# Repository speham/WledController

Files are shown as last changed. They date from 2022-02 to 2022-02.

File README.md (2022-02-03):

# WledController

## Controller based on Esp8266-12F  for https://github.com/Aircoookie/WLED.git 

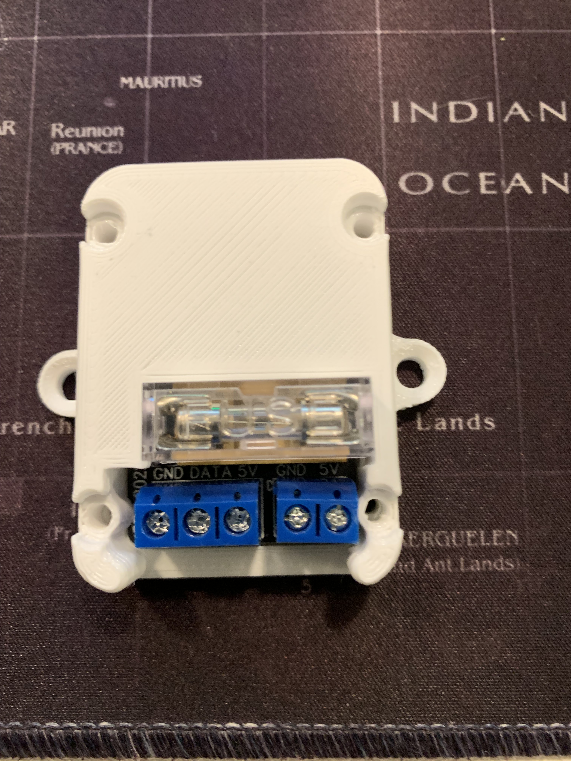
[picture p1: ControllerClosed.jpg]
board


## Settings / Features
- SW Button - GPIO0  
- Data Pin  - GPIO2
- Serial Connection for flashing
- use fuse depending on maximum current of Led stripe (max 5A)
- OTA-Update possible
- small form factor (41x55x21mm)

## Compatible Led Stripes
WS2812B | 5v | RGB
SK6812  | 5v | RGBW

## Connections
Connect 5V/GND to power supply. 5V out should only be used for LED stripes with less than 60 Leds (3.6A - ws2812b)
For longer stripes only the data wire of the stripe should be connected to the controller so + and - of the LED stripe 
is connected to the power supply (common GND for controller and led stripe).

## Flash With Other Firmware
Serial connector on top right side of the board (FTDI adapter necessary to flash)
 - Hold boot and RST button
 - release RST button 
 -> brings the esp8266 in flash mode

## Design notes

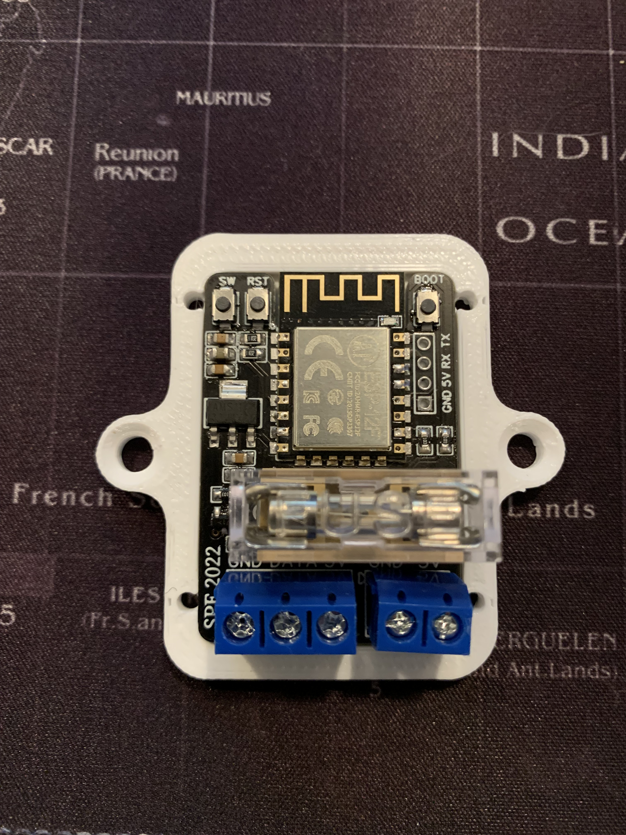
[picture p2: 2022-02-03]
ControllerOpen.jpg

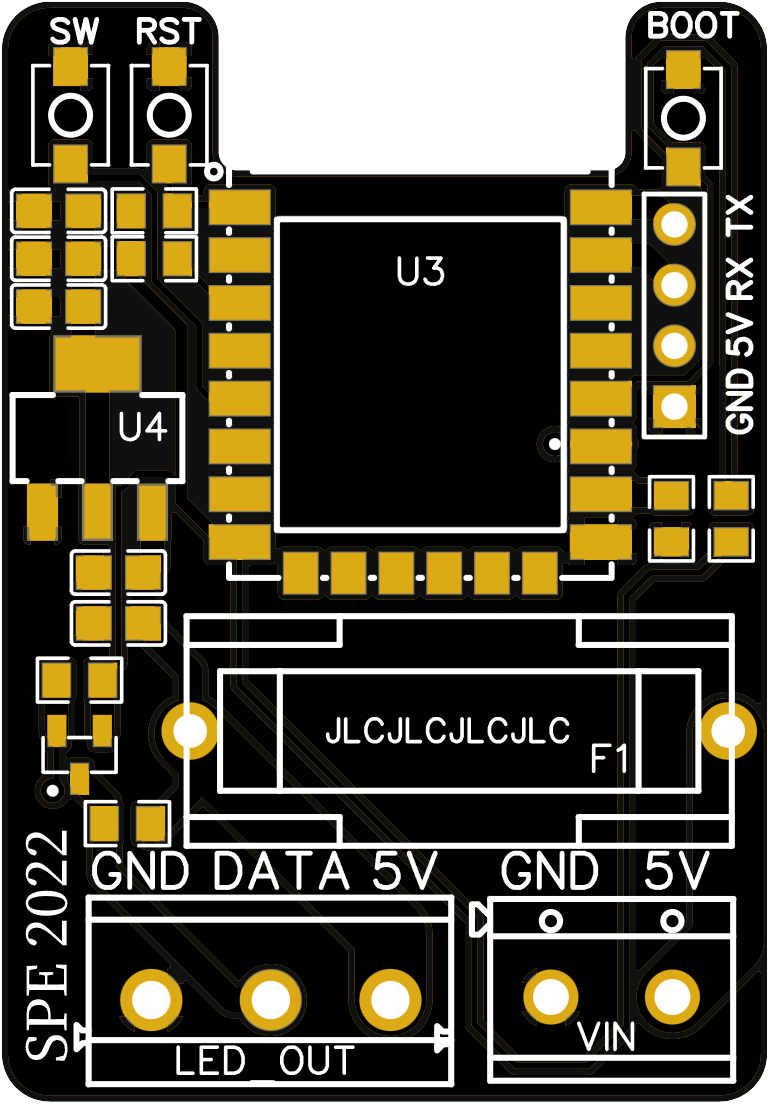
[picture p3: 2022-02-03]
PCB/PCB_V1.png

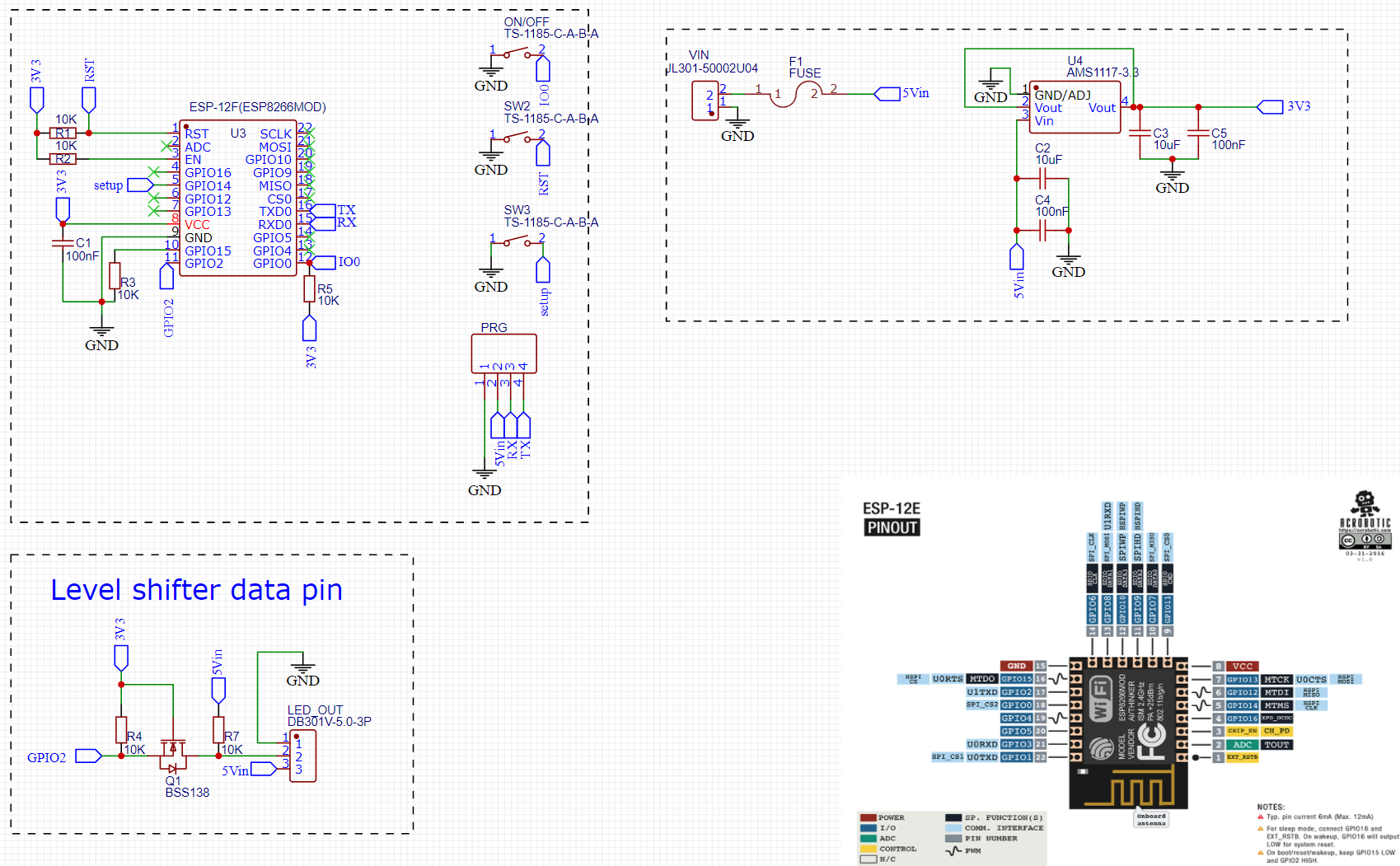
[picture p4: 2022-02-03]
PCB/PCB_V1Sch.png

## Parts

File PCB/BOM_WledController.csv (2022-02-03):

ID | Name | Designator | Footprint | Quantity | Manufacturer Part | Manufacturer | Supplier | Supplier Part | Price
1 | 100nF | C1 | C0805 | 1 | 0805F104M101NT | FH | LCSC | C111591 | 0.014
2 | 10uF | C2,C3 | C0805 | 2 | CL21B106KOQNNNE | SAMSUNG | LCSC | C95841 | 0.031
3 | 100nF | C4,C5 | C0805 | 2 | NL0805B104M500CPBN | HUI JU | LCSC | C720961 | 0.004
4 | FUSE | F1 | FUSE-5X20-PCB | 1
5 | DB301V-5.0-3P | LED_OUT | CONN-TH_DB301V-5.0-3P | 1 | DB301V-5.0-3P | DIBO | LCSC | C395881 | 0.166
6 | TS-1185-C-A-B-A | ON/OFF,SW2,SW3 | SW-SMD_L4.0-W2.9-LS5.0 | 3 | TS-1185-C-A-B-A | XKB Enterprise | LCSC | C561519 | 0.059
7 | 220S-1*4P H=8.5MM Ytype Gold-plated | PRG | HDR-TH_4P-P2.54-V | 1 | 220S-1*4P H=8.5MM Ytype Gold-plated | Ckmtw | LCSC | C124413 | 0.117
8 | BSS138 | Q1 | SOT-23-3_L2.9-W1.3-P1.90-LS2.4-BR | 1 | BSS138 | CJ | LCSC | C78284 | 0.033
9 | 10K | R1,R2,R3,R4,R5,R7 | R0805 | 6 | WR08X1002FTL | WTC | LCSC | C108451 | 0.003
10 | ESP-12F(ESP8266MOD) | U3 | WIFIM-SMD_ESP-12F-ESP8266MOD | 1 | ESP-12F(ESP8266MOD) | Ai-Thinker | LCSC | C82891 | 1.769
11 | AMS1117-3.3 | U4 | SOT-223-3_L6.5-W3.4-P2.30-LS7.0-BR | 1 | AMS1117-3.3 | AMS | LCSC | C6186 | 0.164
12 | JL301-50002U04 | VIN | CONN-TH_JL301-50002U01 | 1 | JL301-50002U04 | JILN(锦凌) | LCSC | C1509679 | 0.084

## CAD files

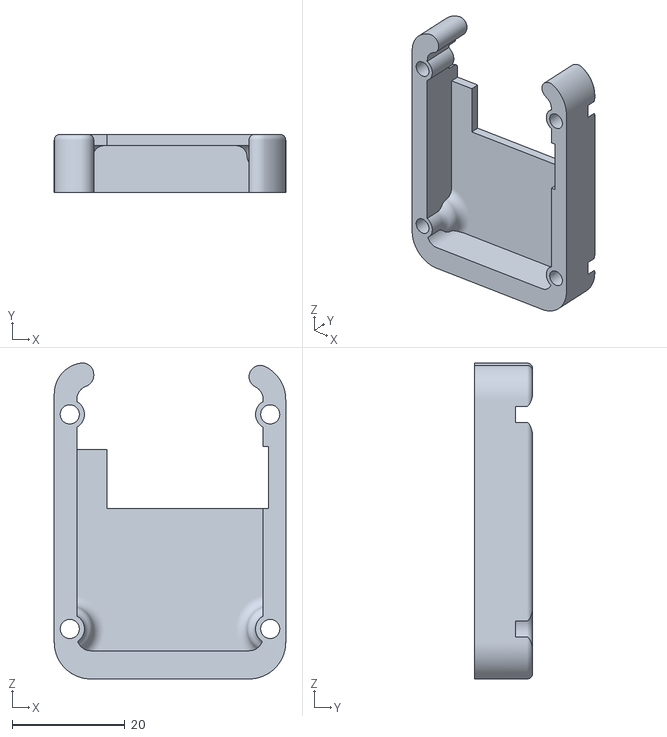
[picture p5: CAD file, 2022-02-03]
Housing/Cover.stl
41.0 x 10.3 x 56.0

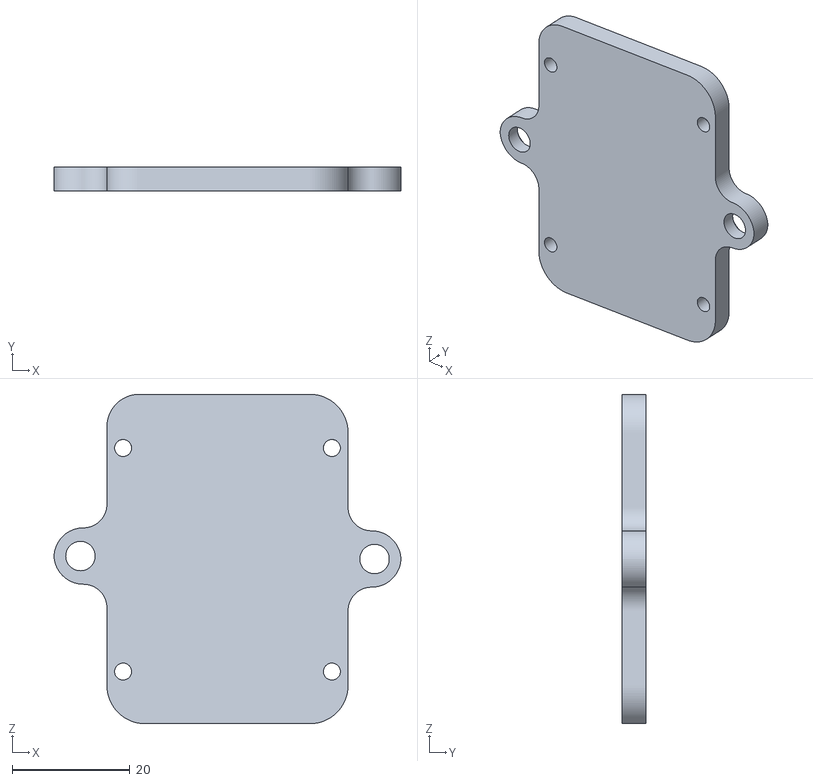
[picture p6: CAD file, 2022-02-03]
Housing/Base.stl
59.0 x 4.10 x 56.0
